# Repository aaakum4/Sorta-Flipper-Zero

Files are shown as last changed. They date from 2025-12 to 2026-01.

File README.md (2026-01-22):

Flipper Image

# Sorta-Flipper-Zero by aaakum4 (Jake)

At the cost of a flipper zero, I thought that I may never own one. Then I found a hackster.io page that went through a full DIY and cheap Flipper Zero and I thought I'd try it myself with some changes. With this project, I should also learn a ton about PCB's and how electronics work.

V1 is a modular based project to ensure that it will work as planned, then, , I will completely custom make it for V2. 

Features: 
- Bluetooth Low Energy (BLE)
- Sub-GHz RF support (433 MHz)
- NFC / RFID functionality
- Infrared (IR) transmit and receive
- On-device display
- Physical navigation and action buttons
- Audible feedback via buzzer
- MicroSD card storage
- USB-C connectivity
- External antenna support

Not included (compared to a standard Flipper): 
- iButton / 1-Wire support - Capacitive touch input
- Internal battery charging and management
- Integrated antennas
- Fully enclosed, consumer-ready housing (I will make one for v2)

## Step 1 - Looking at the Flipper Zero Hardware

Before starting this project, I went through the Flipper Zero hardware documentation to understand how the device is built and what components it uses.

https://docs.flipper.net/zero/development/hardware/tech-specs
https://docs.flipper.net/zero/development/hardware/schematic

<p align="center">

</p>

From this, I created the table below listing the main hardware blocks used in the Flipper Zero.
This table is used as a reference to understand the system, not something to copy directly.

### Flipper Zero – Hardware Component Overview

<p align="center">
Screenshot 2025-12-19 at 7 44 55 pm
</p>

### Simplifying the Design (v1)
To keep the first version realistic and achievable, a few things were intentionally simplified.

#### USB Power Only
The device is powered only through USB, with no internal rechargeable battery.
This removes a lot of complexity around battery charging and safety, and makes early testing much easier. Portability isn’t the focus for the first version.

#### BLE Using a Module or Dev Board
Instead of designing a full BLE RF circuit, this project uses either an STM32WB5MMG module or a NUCLEO-WB55RG during early development.
This avoids antenna tuning issues and lets me focus more on firmware and overall system behaviour.

#### Simpler Sub-1 GHz Antenna
The Flipper Zero uses an antenna multiplexer to optimise different Sub-1 GHz bands. For this project, that part is left out.
A single antenna is used instead, which means reduced range, but much simpler hardware and easier bring-up.

#### Physical Reset Button
Rather than copying the Flipper Zero’s reset button combination logic, this design uses a dedicated reset button.
This keeps the schematic simpler and is more practical while debugging.

## Step 2 - v1 Hardware Selection (Module Based)
Based on the Flipper Zero reference design and the simplifications outlined above, the following components were chosen for the v1 module-based prototype.
This list reflects what will actually be used in the first working version of the project.

V1 - Selected Components:

<p align="center">
Screenshot 2025-12-19 at 8 00 04 pm
</p>

## Step 3 – Schematic Design

With the overall architecture defined, I moved on to creating the full schematic in KiCad. The goal at this stage was to produce a complete, electrically correct design that could realistically be turned into a PCB, while still keeping the project modular and easy to iterate on.

I started by placing the STM32WB5MMGH6TR module and wiring all required power pins according to ST’s reference designs. This included separating the digital and analog supplies, tying VREF+ to VDDA, and correctly handling VBAT and VDDUSB. Decoupling capacitors were added close to each supply pin to ensure stable operation.

Next, the power system was designed around USB-C input. A main 3.3 V rail powers the MCU and core logic, while a second 3.3 V rail is used for external peripherals. 

Peripheral interfaces were then added. Instead of hard-coding specific modules, generic headers were used for NFC, Sub-1 GHz RF, display, IR, vibration, and expansion. These headers are labeled to match common module pinouts, allowing different breakout boards to be tested without changing the core design. Shared buses like SPI were carefully routed with separate chip-select signals.

Finally, the schematic was cleaned up and checked for electrical correctness. ERC warnings were addressed, unused pins were left intentionally for future use, and the design was reviewed to ensure it matched the original goals of being practical, modular, and suitable for a first hardware revision.

<p align="center">
Screenshot 2025-12-20 at 10 05 20 pm
</p>

This step, to be honest, was kinda cooked. I went in a bit over my head with this and it took wayyyy longer than I had hoped and probably needed.

## Step 4 - Schematic fixes and cleanup

After the initial schematic was complete, I spent time going back through it to fix a number of electrical and structural issues flagged by ERC. This step was mainly about correcting mistakes rather than adding new features.

Most of the changes were around power domains, making sure VDD, VDDA, VREF+, VBAT, and VDDUSB were connected correctly and matched the STM32WB module datasheet. I cleaned up grounding, added and adjusted local decoupling capacitors, and removed a few incorrect connections that were previously masking ERC errors instead of solving them properly.

I also fixed the Bluetooth RF path, reworking the RF_OUT pin so it is routed through a DC-blocking capacitor to a u.FL connector. This replaces earlier incorrect handling of the RF pin and makes the onboard BLE functionality usable while keeping the design clean and standards-compliant.

<p align="center">
Screenshot 2025-12-22 at 11 09 07 pm
</p>

<p align="center">
Screenshot 2025-12-22 at 11 08 50 pm
</p>

This is an amazing sight, no ERC errors 🙏🏻

## Step 5 - Sorting and routing the board

I am now a new man...

This was my third time routing a PCB, and it was a mix of improvement… and pain. The Xiao MCU I used for the Macropad and the ESP32-S3-WROOM-1u for the development board don’t come close to the challenge I just faced. The STM32WB5MMG is tiny but packed with pins, making it a real test of patience. That said, I’m finally done, and I couldn’t be happier.

There were multiple reroutes along the way, mostly caused by pin congestion around the MCU and the sheer number of external connectors. Some compromises were necessary, like tighter clearances and smaller vias, but in the end, the board reached a fully routable and manufacturable state.

While it’s not perfect, this routing pass made me really proud of how far I’ve come since the Macropad project. It was a clear reminder that schematics are the easy part—routing is where designs are truly made or broken.

For this project, I worked with a 4-layer board (my first board over 2 layers) to manage density and RF performance, especially around the RF/Bluetooth section. I created a dedicated antenna keep-out zone to avoid copper interference, routed USB D+ and D− as a matched, parallel pair to maintain signal integrity, and widened power traces to 0.5 mm to reduce voltage drop.

Given the tight board size, I had to selectively use smaller vias and reduced trace widths in congested areas to complete the routing without violating design rules. To make assembly easier, I also added silkscreen boxes around each functional module, improving clarity and helping with placement. Looking back, having dedicated GND and +3.3 V layers definitely made this step much more manageable compared to what it would’ve been without them.

### The board

Size: 125mm x 70mm (quite alot bulkier than a normal flipper, I have no clue how they do it)
Vias:
1) Defult: 0.6 x 0.3
2) Smaller (Due to cramped space): 0.45 x 0.2
Routes:
1) Defult: Clearance = 0.2, Width = 0.2
2) Power: Clearance = 0.2, Width = 0.5
3) Smaller: Clearance = 0.2, Width = 0.15

<p align="center">

</p>

#### Layer 1:
<p align="center">

</p>

#### Layer 2: GND
<p align="center">

</p>

#### Layer 3: +3V3
<p align="center">

</p>

#### Layer 4:
<p align="center">

</p>

#### 3D:
<p align="center">

</p>

<p align="center">

</p>

Estimated Time:
~2 hours of planning & component placement
~6 to 8 hours of routing + rerouting
~2 to 3 hours of cleanup, checks, and second-guessing everything

(Plus bonus time staring at the screen being stupid)

## Step ??? - Spontaneous Micro Project

For v2 of the Sorta Flipper Zero, I’ll most likely need to make a copper trace antenna for the NFC. For V1, I’m using a module, but I didn’t want to jump into V2 blindly. I decided to spend some time understanding how the module works, what I can bridge across, and even built my own small NFC card as an introduction to what I’ll need to do in V2.

Here’s the datasheet for the NFC module I hope to use: ST X-NUCLEO-NFC08A1

One thing I quickly noticed is that the antenna matters a lot. The orientation, size, and shape of the coil strongly affect the read range, and even small changes in trace layout or nearby copper can weaken the signal. This made it clear that designing a custom antenna will require careful attention.

I also learned that matching the antenna to the module is critical. The module expects the antenna to have roughly the right inductance; otherwise, communication becomes unreliable. Experimenting with the card showed me how adding or removing a turn in the coil noticeably changes performance.

Using the module is convenient because it handles much of the tuning internally. But seeing it in action made it obvious that if I want a custom copper trace for V2, I’ll need to account for these details myself.

This is the PCB I made from a simple schematic. I originally included an LED, but removed it in the PCB for the sake of readability and clarity. The file is in its own folder.

#### PCB:
<p align="center">

</p>

#### 3D:
<p align="center">

</p>

<p align="center">

</p>

This step is not nesassary at all, but I truly found it really helpful with general understanding of this concept and I think it will be even more helpful when I make v2.

## Parts
Since alot of this iteration will be using modules there isn't that much soldering. Here is the parts list from JLCPCB PCBA.

<p align="center">

</p>

## Firmware

Generating OTP Data (Flipper Zero)

This project uses the Flipper Zero firmware OTP generation script (scripts/otp.py) derived from the official Flipper Zero firmware repository (licensed under GPL-3.0) to generate device-specific OTP data.

### Example:

```
cd flipperzero-firmware/scripts

./otp.py generate \
  --version $((0x0c)) \
  --firmware $((0x07)) \
  --body $((0x09)) \
  --connect $((0x06)) \
  --display "mgg" \
  --color "transparent" \
  --region "world" \
  --name "Greg" \
  myotp
```

**Warning**: OTP memory is one-time programmable.
Flashing incorrect data may permanently affect the device.

### Installing Firmware via qFlipper

https://github.com/flipperdevices/qFlipper.git
Firmware installation is performed using qFlipper, the official Flipper Zero desktop application.

1. Install qFlipper from the official Flipper Zero website
2. Connect the device via USB
3. Select the appropriate firmware package
4. Follow on-screen flashing instructions

This project may reference prebuilt firmware or OTP data derived from the Flipper Zero firmware repository. All such components remain licensed under GPL-3.0, and source code is provided in accordance with that license.

## ⚠️ Problem solving

The NFC chip used on the X‑NUCLEO expansion board is the ST25R3916B, which has a different IC identity value to the ST25R3916 used in the Flipper Zero. Although the two chips share the same register map and functionality, the firmware performs an identity check during initialisation, causing the driver to fail when the B variant is detected.

To resolve this, I forked the official Flipper Zero firmware repository (https://github.com/flipperdevices/flipperzero-firmware) and modified the NFC driver to accept the ST25R3916B IC identity. This allows the existing firmware to operate correctly with the alternative NFC hardware without affecting functionality.

The modified source code is available here:
https://github.com/aaakum4/flipperzero-firmware.git

## License

This project is licensed under the GNU General Public License v3.0 (GPL-3.0).

This project includes and is derived from code from:
- flipperzero-firmware by skotopes (Top contributor)
  Licensed under GPL-3.0

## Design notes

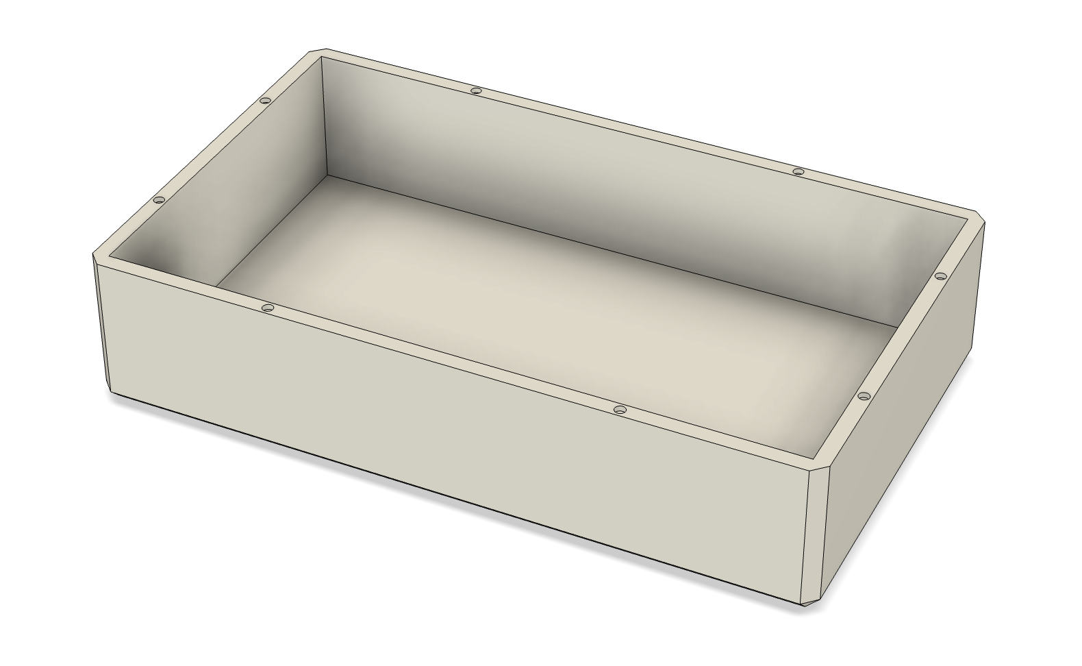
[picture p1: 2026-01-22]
CAD/Housing/Housing Bottom.png

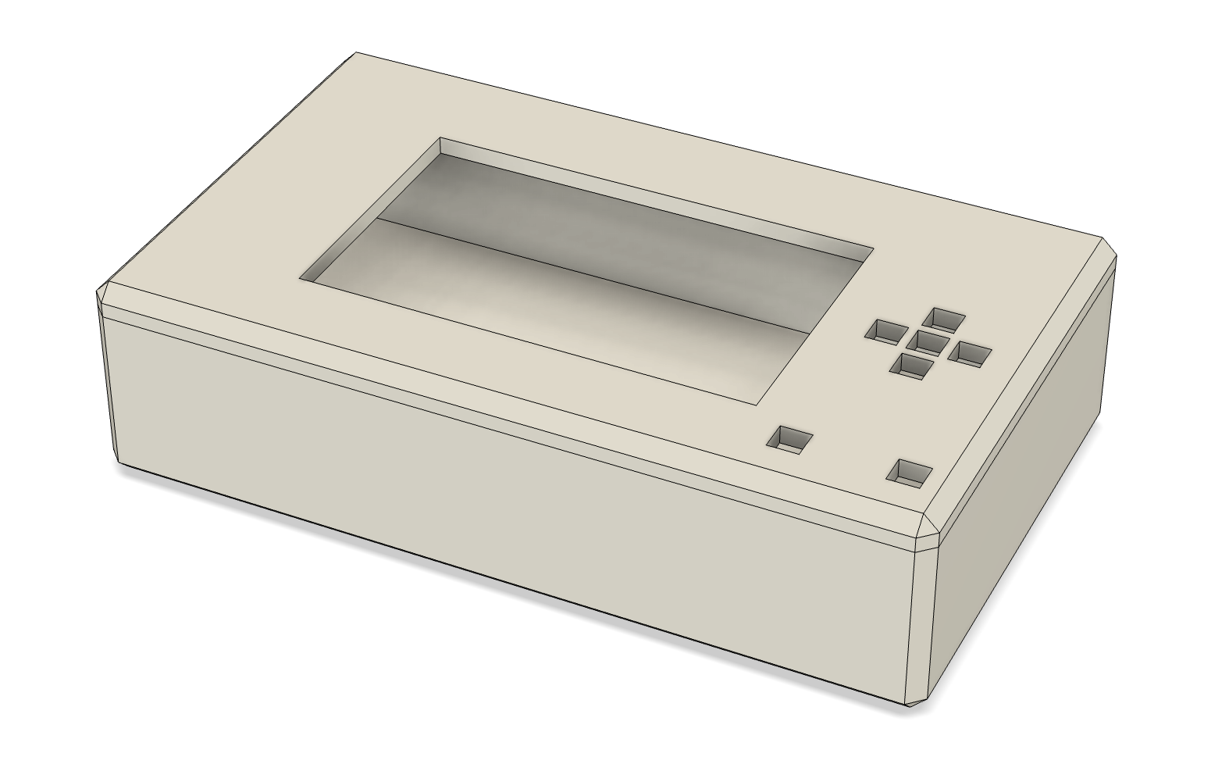
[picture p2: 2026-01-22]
CAD/Housing/Housing.png

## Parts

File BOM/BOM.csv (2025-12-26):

JLCPCB BOM Tool - BOM Matching
BOM name：Fipper Zero-JLCPCB Assembly Order.xlsx |  |  | Download Time：2025-12-26 21:10:08 |  |  |  | * Our matching results are updated in real-time, but stock and prices may change. If it's been over 24 hours, please re-match before placing your order.
PCB Assembled Qty：5 |  |  | Est. Total Price：65.3443
Your BOM |  |  |  |  | Matched Parts |  |  |  |  |  |  | Order Information
Top Designator | Bottom Designator | Comment | Footprint | JLCPCB Part # | Matches | Part # | Manufacturer | Footprint | Description | Category | Warning | JLCPCB Part # | Product link | Lib Type | Qty | Source | Total Price ($)
BZ1 |  | Buzzer | BUZ-TH_BD9.0-P4.00-D0.6-FD |  | Select by Customer | QMB-09B-03 | Jiangsu Huaneng Elec | 插件,D=9mm | -20℃~+70℃ 2.7kHz 2V~5V 3V 5.7mm 50mA 85dB 9mm Electromagnetic Passive (Externally Driven) Plugin,D=9mm Buzzers ROHS | Buzzers |  | C96256 | https://jlcpcb.com/partdetail/Jiangsu_HuanengElec-QMB_09B03/C96256 | Extended | 6 | 6 JLCPCB | 0.6714
C2 |  | 1uF | C_0603_1608Metric |  | Select by Customer | CL10A105KA8NNNC | Samsung Electro-Mechanics | 0603 | 1uF 25V X5R ±10% 0603 Multilayer Ceramic Capacitors MLCC - SMD/SMT ROHS | Multilayer Ceramic Capacitors MLCC - SMD/SMT |  | C5673 | https://jlcpcb.com/partdetail/6132-CL10A105KA8NNNC/C5673 | Extended | 20 | 20 JLCPCB | 0.086
C4,C5,C7,C6,C3,C1 |  | 100nF | C_0603_1608Metric |  | Select by Customer | CL10B104KA8NNNC | Samsung Electro-Mechanics | 0603 | 100nF 25V X7R ±10% 0603 Multilayer Ceramic Capacitors MLCC - SMD/SMT ROHS | Multilayer Ceramic Capacitors MLCC - SMD/SMT |  | C1590 | https://jlcpcb.com/partdetail/1942-CL10B104KA8NNNC/C1590 | Extended | 40 | 40 JLCPCB | 0.132
C8 |  | 4.7uF | C_0805_2012Metric |  | Select by Customer | CL21A475KOFNNNE | Samsung Electro-Mechanics | 0805 | 16V 4.7uF X5R ±10% 0805 Multilayer Ceramic Capacitors MLCC - SMD/SMT ROHS | Multilayer Ceramic Capacitors MLCC - SMD/SMT |  | C1746 | https://jlcpcb.com/partdetail/2098-CL21A475KOFNNNE/C1746 | Extended | 20 | 20 JLCPCB | 0.288
CP3,CP1,CP2 |  | 10u | C_0805_2012Metric |  | Select by Customer | CL21A106KAYNNNE | Samsung Electro-Mechanics | 0805 | 10uF 25V X5R ±10% 0805 Multilayer Ceramic Capacitors MLCC - SMD/SMT ROHS | Multilayer Ceramic Capacitors MLCC - SMD/SMT |  | C15850 | https://jlcpcb.com/partdetail/16532-CL21A106KAYNNNE/C15850 | Basic | 25 | 25 JLCPCB | 0.2475
D1 |  | D_Schottky | D_SOD-123 |  | Select by Customer | SS14 | MDD(Microdiode Semiconductor) | SMA(DO-214AC) | -55℃~+150℃ 1A 25A 300uA@40V 40V 550mV@1A Independent SMA(DO-214AC) Schottky Diodes ROHS | Schottky Diodes |  | C2480 | https://jlcpcb.com/partdetail/MDD_Microdiode_Semiconductor-SS14/C2480 | Basic | 15 | 15 JLCPCB | 0.2265
J5 |  | Conn_02x04_Odd_Even | PinHeader_2x04_P2.54mm_Vertical |  | Select by Customer | 2.54-1*40P直针 | BOOMELE(Boom Precision Elec) | 插件,P=2.54mm | -25℃~+85℃ 1 1x40P 2.54mm 2.5mm 3A 3mm 40P 6mm Black Brass Gold Pin Header Through Hole Plugin,P=2.54mm Pin Headers ROHS | Pin Headers | 1.Multiple lines in the BOM have been matched to the same part. Please check if the matching is correct. ; | C2337 | https://jlcpcb.com/partdetail/2712-2_54_1_40P/C2337 | Extended | 0 | 0 JLCPCB | 0
J6 |  | iButtonConnector | PinHeader_1x02_P2.54mm_Vertical |  | Select by Customer | 2.54-1*40P直针 | BOOMELE(Boom Precision Elec) | 插件,P=2.54mm | -25℃~+85℃ 1 1x40P 2.54mm 2.5mm 3A 3mm 40P 6mm Black Brass Gold Pin Header Through Hole Plugin,P=2.54mm Pin Headers ROHS | Pin Headers | 1.Multiple lines in the BOM have been matched to the same part. Please check if the matching is correct. ; | C2337 | https://jlcpcb.com/partdetail/2712-2_54_1_40P/C2337 | Extended | 0 | 0 JLCPCB | 0
J7 |  | MicroSDCard | PinHeader_1x06_P2.54mm_Vertical |  | Select by Customer | 2.54-1*40P直针 | BOOMELE(Boom Precision Elec) | 插件,P=2.54mm | -25℃~+85℃ 1 1x40P 2.54mm 2.5mm 3A 3mm 40P 6mm Black Brass Gold Pin Header Through Hole Plugin,P=2.54mm Pin Headers ROHS | Pin Headers | 1.Multiple lines in the BOM have been matched to the same part. Please check if the matching is correct. ; | C2337 | https://jlcpcb.com/partdetail/2712-2_54_1_40P/C2337 | Extended | 0 | 0 JLCPCB | 0
J8 |  | Switch | PinHeader_1x02_P2.54mm_Vertical |  | Select by Customer | 2.54-1*40P直针 | BOOMELE(Boom Precision Elec) | 插件,P=2.54mm | -25℃~+85℃ 1 1x40P 2.54mm 2.5mm 3A 3mm 40P 6mm Black Brass Gold Pin Header Through Hole Plugin,P=2.54mm Pin Headers ROHS | Pin Headers | 1.The comment (2.54-1*40P直针) of this part does not match the one (Switch) provided in your BOM. Please confirm; 2.Multiple lines in the BOM have been matched to the same part. Please check if the matching is correct. ; | C2337 | https://jlcpcb.com/partdetail/2712-2_54_1_40P/C2337 | Extended | 0 | 0 JLCPCB | 0
J14 |  | Conn_01x13 | PinHeader_1x13_P2.54mm_Vertical |  | Select by Customer | 2.54-1*40P直针 | BOOMELE(Boom Precision Elec) | 插件,P=2.54mm | -25℃~+85℃ 1 1x40P 2.54mm 2.5mm 3A 3mm 40P 6mm Black Brass Gold Pin Header Through Hole Plugin,P=2.54mm Pin Headers ROHS | Pin Headers | 1.Multiple lines in the BOM have been matched to the same part. Please check if the matching is correct. ; | C2337 | https://jlcpcb.com/partdetail/2712-2_54_1_40P/C2337 | Extended | 0 | 0 JLCPCB | 0
J15 |  | Conn_01x18 | Flipper_Zero_Straight |  | Select by Customer | 2.54-1*40P直针 | BOOMELE(Boom Precision Elec) | 插件,P=2.54mm | -25℃~+85℃ 1 1x40P 2.54mm 2.5mm 3A 3mm 40P 6mm Black Brass Gold Pin Header Through Hole Plugin,P=2.54mm Pin Headers ROHS | Pin Headers | 1.Multiple lines in the BOM have been matched to the same part. Please check if the matching is correct. ; | C2337 | https://jlcpcb.com/partdetail/2712-2_54_1_40P/C2337 | Extended | 0 | 0 JLCPCB | 0
J16 |  | Conn_Coaxial | U.FL_Hirose_U.FL-R-SMT-1_Vertical |  | Select by Customer | U.FL-R-SMT-1(10) | HRS(Hirose) | SMD | -40℃~+90℃ 1 1.25mm 2mm 50Ω 6GHz Board Side IPEX Male Pin SMD Coaxial Connectors (RF) ROHS | Coaxial Connectors (RF) |  | C88373 | https://jlcpcb.com/partdetail/HRS_Hirose-U_FL_R_SMT_1_10/C88373 | Extended | 5 | 5 JLCPCB | 0.947
R17,RX1,R7,R12,R4,R5,R19,R6,R10,R9,R8,R2,R14,R3,RX2,R13,R16,R21,R15,R20,R11,R1 |  | 47 | R_0603_1608Metric |  | Select by Customer | GZ1608D601TF | Sunlord | 0603 | -55℃~+125℃ 1 200mA 450mΩ 600Ω@100MHz ±25% 0603 Ferrite Beads ROHS | Ferrite Beads | 1.The comment (GZ1608D601TF) of this part does not match the one (47) provided in your BOM. Please confirm; 2.There may be multiple types of parts, but one type of part has been matched. Please check.; | C1002 | https://jlcpcb.com/partdetail/Sunlord-GZ1608D601TF/C1002 | Basic | 116 | 116 JLCPCB | 0.7772
R18,RU2,RU1,RP1 |  | 5.1k | R_0603_1608Metric |  | Select by Customer | 0402WGF5101TCE | UNI-ROYAL(Uniroyal Elec) | 0402 | -55℃~+155℃ 5.1kΩ 50V 62.5mW Thick Film Resistor ±1% ±100ppm/℃ 0402 Chip Resistor - Surface Mount ROHS | Chip Resistor - Surface Mount | 1.The comment (0402WGF5101TCE) of this part does not match the one (5.1k) provided in your BOM. Please confirm; 2.There may be multiple types of parts, but one type of part has been matched. Please check.; | C25905 | https://jlcpcb.com/partdetail/26648-0402WGF5101TCE/C25905 | Basic | 30 | 30 JLCPCB | 0.015
R22 |  | 10 | R_0603_1608Metric |  | Select by Customer | 0603WAF100JT5E | UNI-ROYAL(Uniroyal Elec) | 0603 | -55℃~+155℃ 100mW 10Ω 75V Thick Film Resistor ±1% ±400ppm/℃ 0603 Chip Resistor - Surface Mount ROHS | Chip Resistor - Surface Mount | 1.The comment (0603WAF100JT5E) of this part does not match the one (10) provided in your BOM. Please confirm; | C22859 | https://jlcpcb.com/partdetail/23586-0603WAF100JT5E/C22859 | Basic | 20 | 20 JLCPCB | 0.02
R23 |  | 0 | R_0402_1005Metric |  | Select by Customer | PA0402-R-070RL | YAGEO | 0402 | -55℃~+125℃ 0Ω 62.5mW ±150ppm/℃ 0402 Chip Resistor - Surface Mount ROHS | Chip Resistor - Surface Mount |  | C4044221 | https://jlcpcb.com/partdetail/YAGEO-PA0402_R070RL/C4044221 | Extended | 7 | 7 JLCPCB | 0.9121
SW4,SW5,SW1,SW3,SW7,SW6,SW2 |  | SW_Push | SW_PUSH_6mm |  | Select by Customer | HX-6x6x7.3-TP FT square button | hanxia | SMD,6x6mm | SMD,6x6mm Tactile Switches ROHS |  |  | C49234152 | https://jlcpcb.com/partdetail/C49234152 | Extended | 35 | 35 JLCPCB | 0.9765
U1 |  | STM32WB5MMGH6TR | LCC-LGA-86_L11.0-W7.3_STM32WB5MMGH6TR |  | Select by Customer | STM32WB5MMGH6TR | STMicroelectronics | LFLGA-86 | -40℃~+85℃ -96dBm 1.71V~3.6V 2.4GHz 2.4GHz~2.4835GHz 2Mbps 6dBm SPI ZigBee LFLGA-86 RF Transceiver ICs ROHS | RF Transceiver ICs |  | C5184586 | https://jlcpcb.com/partdetail/STMicroelectronics-STM32WB5MMGH6TR/C5184586 | Extended | 5 | 5 JLCPCB | 58.108
UP2,UP1 |  | AP2112K-3.3 | SOT-23-5 |  | Select by Customer | AP2112K-3.3TRG1 | TECH PUBLIC | SOT-23-5 | -、50dB@(10kHz)、70dB@(1kHz)、70dB@(1kHz)、70dB@(1kHz)、75dB@(1kHz)、75dB@(1kHz) 1.5uA、2uA、2uA、5uA、5uA、10uA、10uA、25uA 1、1、1、1、1、1 200mA、300mA、500mA、500mA、600mA、600mA、600mA、800mA 200mV@(300mA)、300mV@(100mA)、320mV@(600mA)、320mV@(600mA)、350mV@(100mA)、400mV@(800mA)、420mV@(100mA)、800mV@(600mA) 3.3V、1.2V、2.5V、3V、5V、3V、3V、3V 5.5V、5.5V、5.5V、5.5V、6V、20V、20V、24V Fixed、Fixed、Fixed、Fixed、Fixed、Fixed、Fixed、Fixed Over Temperature Protection、Over Current Protection、Over Temperature Protection、Ove | Voltage Regulators - Linear, Low Drop Out (LDO) Regulators |  | C23380830 | https://jlcpcb.com/partdetail/TECHPUBLIC-AP2112K_33TRG1/C23380830 | Extended | 12 | 12 JLCPCB | 1.0776
USB1 |  | USB_C_Receptacle_USB2.0_16P | USB_C_Receptacle_HRO_TYPE-C-31-M-12 |  | Select by Customer | TYPE-C-31-M-12 | Korean Hroparts Elec | SMD | -30℃~+80℃ 1 10,000 cycles 16P 20V 5A 7.35mm Female Surface Mount, Right Angle Type-C SMD USB Connectors ROHS | USB Connectors |  | C165948 | https://jlcpcb.com/partdetail/Korean_HropartsElec-TYPE_C_31_M12/C165948 | Extended | 5 | 5 JLCPCB | 0.8595
EBay | Cost (USD) | Link
5V Mini Vibration Motor Module with High-Low Level PWM Control | 4.66 | https://www.ebay.com.au/itm/176796753894
Total: | 4.66
AliExpress | Cost (USD) | Link
125KHz RFID Module | 2.9 | https://www.aliexpress.com/item/1005006440663319.html?mp=1
LED Display | 4.89 | https://www.aliexpress.com/item/1005006160620381.html?mp=1
RF Transmitter and Reader | 1.07 | https://www.aliexpress.com/item/1005007728215137.html?mp=1
Total: | 8.86
DigiKey | Cost (USD) | Link
X-Nucleo NFC | 39.72 | https://www.digikey.com.au/en/products/detail/stmicroelectronics/X-NUCLEO-NFC08A1/16962233
STM32WB5MMGH6TR | 12.86 | https://www.digikey.com.au/en/products/detail/stmicroelectronics/STM32WB5MMGH6TR/13592597
Micro SD CARD DFR0229 | 5.51 | https://www.digikey.com.au/en/products/detail/dfrobot/DFR0229/6588460
Total: | 58.09

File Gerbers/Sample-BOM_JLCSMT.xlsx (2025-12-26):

Comment | Designator | Footprint | JLCPCB Part #（optional）
100uF | C1 | CAP-SMD_L3.5-W2.8 | C16133
15K | R5,R6 | R0603 | C22809
DC-005-20A_C136744 | DC1 | DC-IN-TH_DC-005-20A | C136744
Header-Female-2.54_1x8 | P2,P3 | HDR-TH_8P-P2.54-V | C27438
K2-1102DP-C4SW-04 | SW1 | KEY-TH_4P-L6.0-W6.0-P4.50-LS6.5 | C110153
ATMEGA328P-PU | U1 | DIP-28_L34.6-W7.3-P2.54-LS10.2-BL | C33901
670688000 | USB1 | USB-B-TH_67068-8000 | C114097

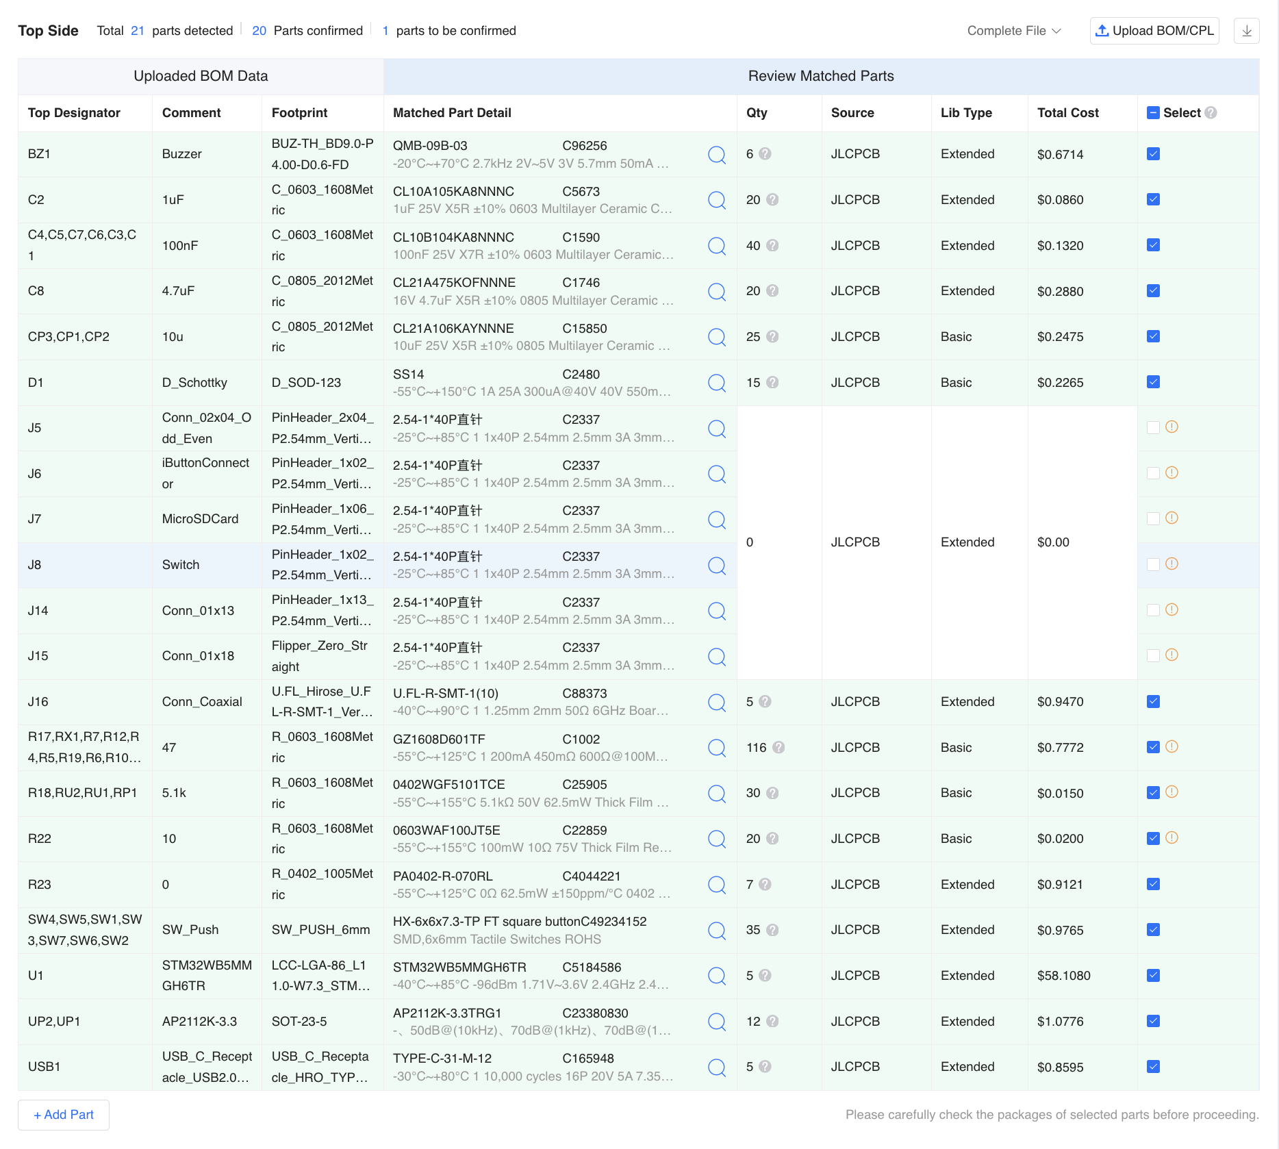
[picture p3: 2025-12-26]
BOM/BOM Image.png

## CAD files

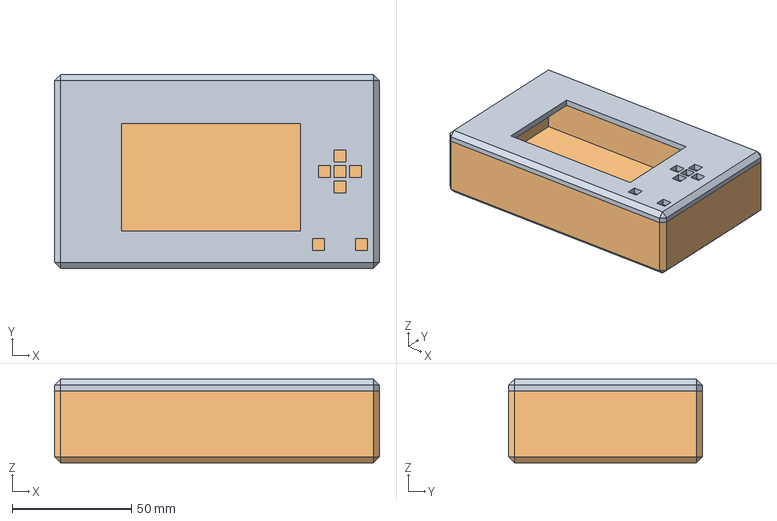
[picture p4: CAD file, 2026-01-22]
CAD/Housing/Basic Housing.step
136.0 x 81.0 x 35.0 mm

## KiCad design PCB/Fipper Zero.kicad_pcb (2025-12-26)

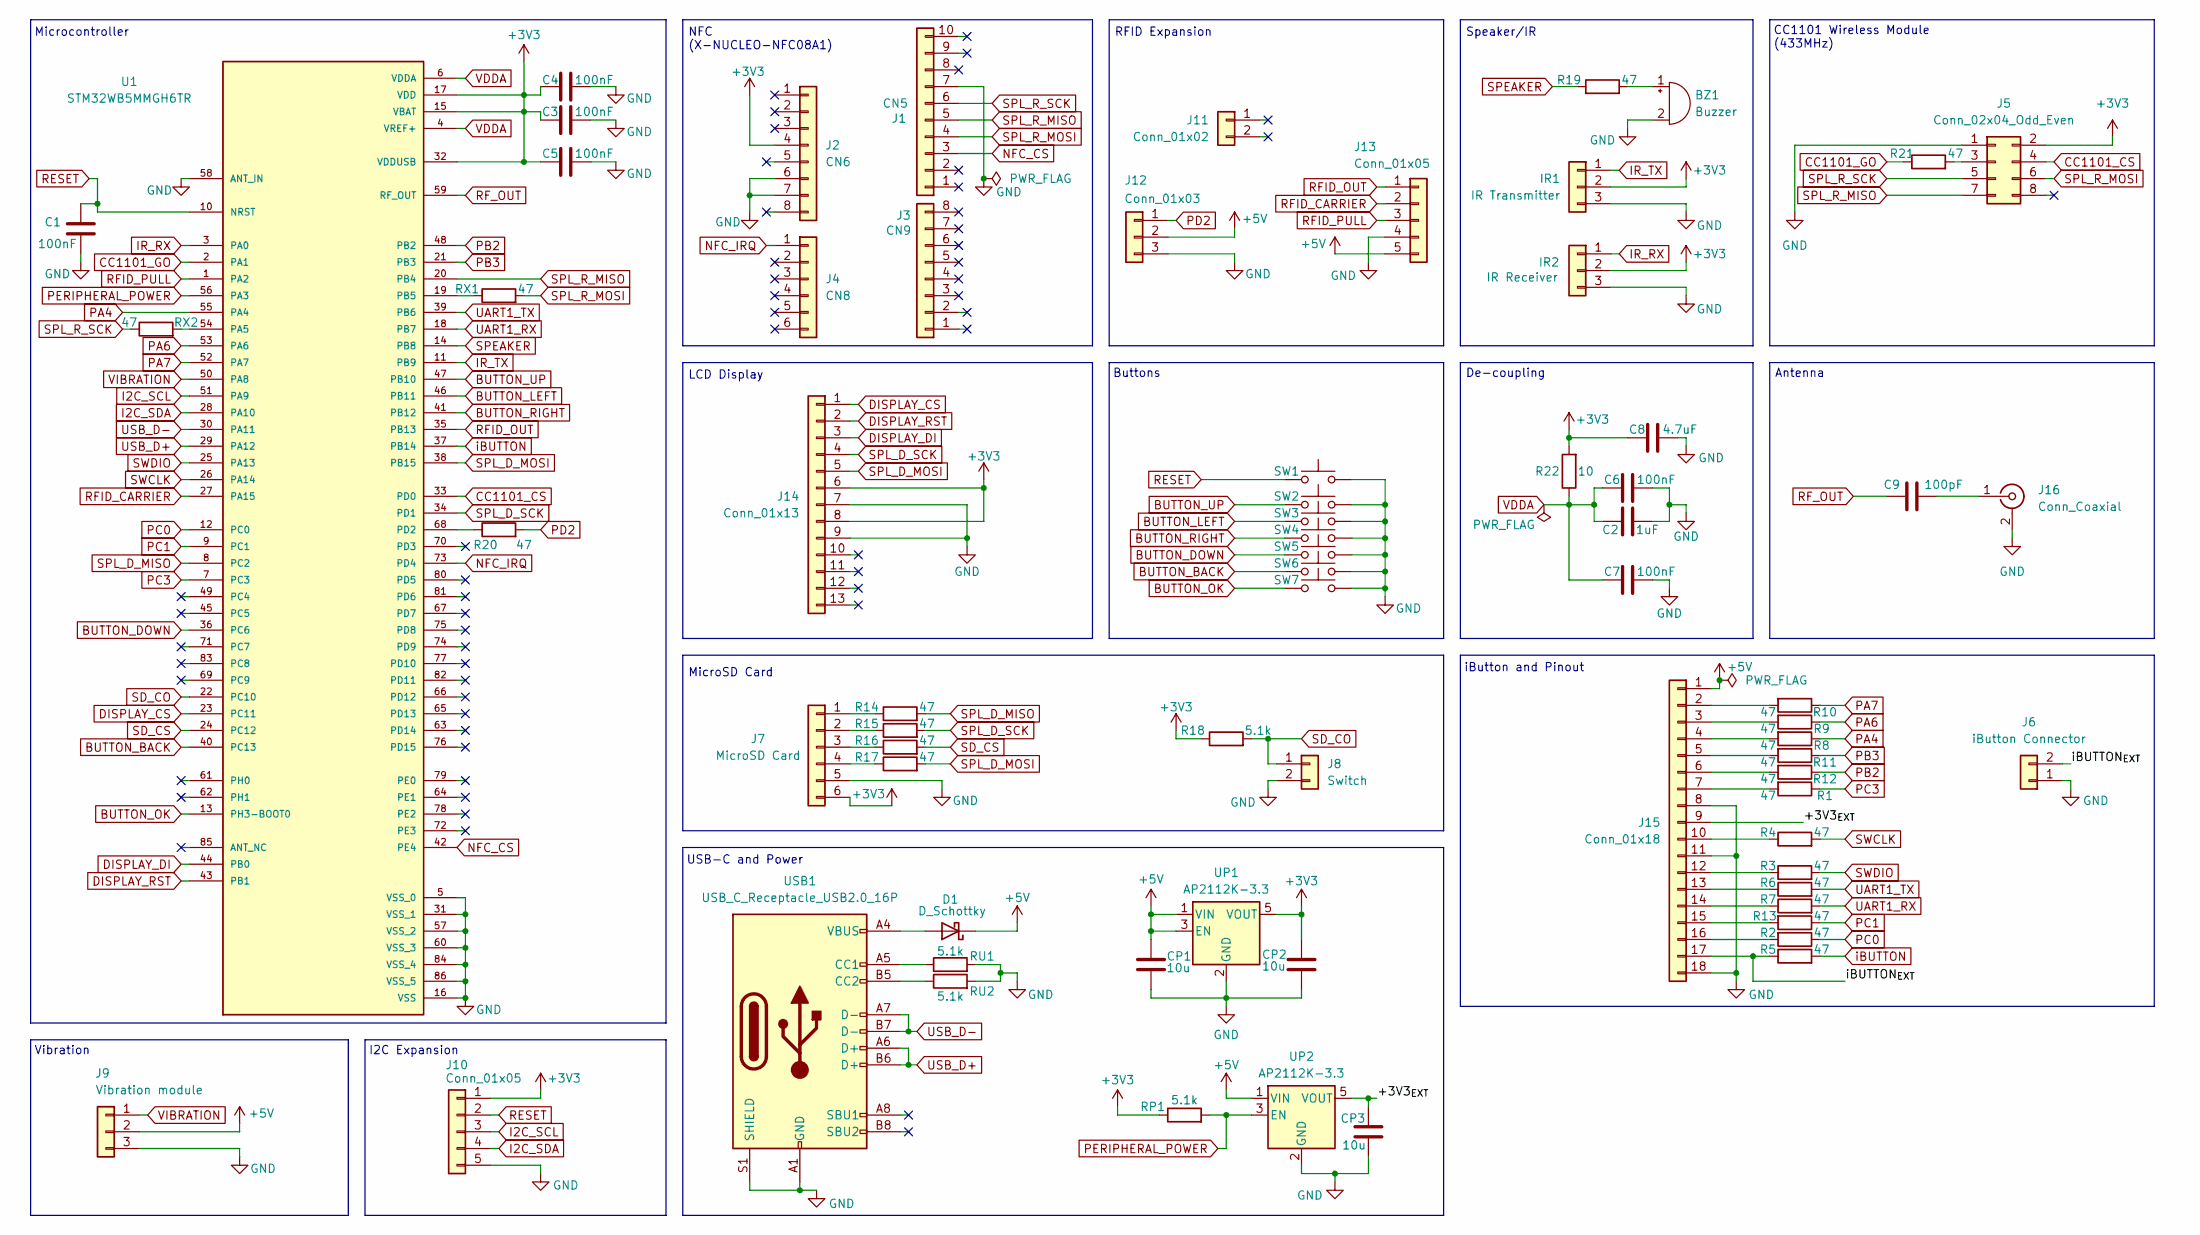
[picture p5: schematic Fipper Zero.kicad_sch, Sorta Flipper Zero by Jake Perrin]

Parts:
BZ1: Buzzer; BUZ-TH_BD9.0-P4.00-D0.6-FD
C1, C3, C4, C5, C6, C7: 100nF; C_0603_1608Metric
C2: 1uF; C_0603_1608Metric
C8: 4.7uF; C_0805_2012Metric
C9: 100pF; C_0402_1005Metric
CP1, CP2, CP3: 10u; C_0805_2012Metric
D1: D_Schottky; D_SOD-123
IR1: IR Transmitter; PinHeader_1x03_P2.54mm_Vertical
IR2: IR Receiver; PinHeader_1x03_P2.54mm_Vertical
J1: CN5; PinHeader_1x10_P2.54mm_Vertical
J2: CN6; PinHeader_1x08_P2.54mm_Vertical
J3: CN9; PinHeader_1x08_P2.54mm_Vertical
J4: CN8; PinHeader_1x06_P2.54mm_Vertical
J5: Conn_02x04_Odd_Even; PinHeader_2x04_P2.54mm_Vertical
J6: iButton Connector; PinHeader_1x02_P2.54mm_Vertical
J7: MicroSD Card; PinHeader_1x06_P2.54mm_Vertical
J8: Switch; PinHeader_1x02_P2.54mm_Vertical
J9: Vibration module; PinHeader_1x02_P2.54mm_Vertical
J10, J13: Conn_01x05; PinHeader_1x05_P2.54mm_Vertical
J11: Conn_01x02; PinHeader_1x02_P2.54mm_Vertical
J12: Conn_01x03; PinHeader_1x03_P2.54mm_Vertical
J14: Conn_01x13; PinHeader_1x13_P2.54mm_Vertical
J15: Conn_01x18; PinHeader_1x18_P2.54mm_Vertical
J16: Conn_Coaxial; U.FL_Hirose_U.FL-R-SMT-1_Vertical
R1, R2, R3, R4, R5, R6, R7, R8, R9, R10, R11, R12, R13, R14, R15, R16, R17, R19, R20, R21: 47; R_0603_1608Metric
R18: 5.1k; R_0603_1608Metric
R22: 10; R_0603_1608Metric
RP1: 5.1k; R_0603_1608Metric
RU1, RU2: 5.1k; R_0603_1608Metric
RX1, RX2: 47; R_0603_1608Metric
SW1, SW2, SW3, SW4, SW5, SW6, SW7: SW_Push; SW_PUSH_6mm
U1: STM32WB5MMGH6TR; LCC-LGA-86_L11.0-W7.3_STM32WB5MMGH6TR; PARTREV 8
UP1, UP2: AP2112K-3.3; SOT-23-5
USB1: USB_C_Receptacle_USB2.0_16P; USB_C_Receptacle_HRO_TYPE-C-31-M-12

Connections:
+3V3: C3.1, C4.1, C5.1, C8.1, CP2.1, IR1.2, IR2.2, J2.4, J5.2, J7.6, J10.1, J14.6, J14.8, R18.1, R22.2, RP1.1, U1.15 (VBAT), U1.17 (VDD), U1.32 (VDDUSB), UP1.5 (VOUT)
+5V: CP1.1, D1.1 (K), J9.2, J12.2, J13.5, J15.1, UP1.1 (VIN), UP1.3 (EN), UP2.1 (VIN)
/+3V3_{EXT}: CP3.1, J15.9, UP2.5 (VOUT)
/iBUTTON_{EXT}: J6.2, J15.17, R5.1
BUTTON_BACK: SW6.1, U1.40 (PC13)
BUTTON_DOWN: SW5.1, U1.36 (PC6)
BUTTON_LEFT: SW3.1, U1.46 (PB11)
BUTTON_OK: SW7.1, U1.13 (PH3-BOOT0)
BUTTON_RIGHT: SW4.1, U1.41 (PB12)
BUTTON_UP: SW2.1, U1.47 (PB10)
CC1101_CS: J5.4, U1.33 (PD0)
CC1101_GO: R21.1, U1.2 (PA1)
DISPLAY_CS: J14.1, U1.23 (PC11)
DISPLAY_DI: J14.3, U1.44 (PB0)
DISPLAY_RST: J14.2, U1.43 (PB1)
GND: BZ1.2 (-), C1.2, C2.2, C3.2, C4.2, C5.2, C6.2, C7.2, C8.2, CP1.2, CP2.2, CP3.2, IR1.3, IR2.3, J1.7, J2.6, J2.7, J5.1, J6.1, J7.5, J8.2, J9.3, J10.5, J12.3, J13.4, J14.7, J14.9, J15.8, J15.11, J15.18, J16.2 (Ext), RU1.2, RU2.2, SW1.2, SW2.2, SW3.2, SW4.2, SW5.2, SW6.2, SW7.2, U1.5 (VSS_0), U1.16 (VSS), U1.31 (VSS_1), U1.57 (VSS_2), U1.58 (ANT_IN), U1.60 (VSS_3), U1.84 (VSS_4), U1.86 (VSS_5), UP1.2 (GND), UP2.2 (GND), USB1.A1 (GND), USB1.A12 (GND), USB1.B1 (GND), USB1.B12 (GND), USB1.S1 (SHIELD)
I2C_SCL: J10.3, U1.51 (PA9)
I2C_SDA: J10.4, U1.28 (PA10)
IR_RX: IR2.1, U1.3 (PA0)
IR_TX: IR1.1, U1.11 (PB9)
NFC_CS: J1.3, U1.42 (PE4)
NFC_IRQ: J4.1, U1.73 (PD4)
unnamed: BZ1.1 (+), R19.2
unnamed: D1.2 (A), USB1.A4 (VBUS), USB1.A9 (VBUS), USB1.B4 (VBUS), USB1.B9 (VBUS)
unnamed: J5.3, R21.2
unnamed: J7.1, R14.1
unnamed: J7.2, R15.1
unnamed: J7.3, R16.1
unnamed: J7.4, R17.1
unnamed: J15.2, R10.2
unnamed: J15.3, R9.2
unnamed: J15.4, R8.2
unnamed: J15.5, R11.2
unnamed: J15.6, R12.2
unnamed: J15.7, R1.2
unnamed: J15.10, R4.1
unnamed: J15.12, R3.1
unnamed: J15.13, R6.1
unnamed: J15.14, R7.1
unnamed: J15.15, R13.2
unnamed: J15.16, R2.2
unnamed 41: C9.2, J16.1 (In); also elsewhere on the board
unnamed: RX2.2, U1.54 (PA5)
unnamed: RX1.1, U1.19 (PB5)
unnamed: R20.1, U1.68 (PD2)
unnamed: RU1.1, USB1.A5 (CC1)
unnamed: RU2.1, USB1.B5 (CC2)
PA4: R8.1, U1.55 (PA4)
PA6: R9.1, U1.53 (PA6)
PA7: R10.1, U1.52 (PA7)
PB2: R12.1, U1.48 (PB2)
PB3: R11.1, U1.21 (PB3)
PC0: R2.1, U1.12 (PC0)
PC1: R13.1, U1.9 (PC1)
PC3: R1.1, U1.7 (PC3)
PD2: J12.1, R20.2
PERIPHERAL_POWER: RP1.2, U1.56 (PA3), UP2.3 (EN)
RESET: C1.1, J10.2, SW1.1, U1.10 (NRST)
RFID_CARRIER: J13.2, U1.27 (PA15)
RFID_OUT: J13.1, U1.35 (PB13)
RFID_PULL: J13.3, U1.1 (PA2)
RF_OUT: C9.1, U1.59 (RF_OUT); also elsewhere on the board
SD_CO: J8.1, R18.2, U1.22 (PC10)
SD_CS: R16.2, U1.24 (PC12)
SPEAKER: R19.1, U1.14 (PB8)
SPL_D_MISO: R14.2, U1.8 (PC2)
SPL_D_MOSI: J14.5, R17.2, U1.38 (PB15)
SPL_D_SCK: J14.4, R15.2, U1.34 (PD1)
SPL_R_MISO: J1.5, J5.7, U1.20 (PB4)
SPL_R_MOSI: J1.4, J5.6, RX1.2
SPL_R_SCK: J1.6, J5.5, RX2.1
SWCLK: R4.2, U1.26 (PA14)
SWDIO: R3.2, U1.25 (PA13)
UART1_RX: R7.2, U1.18 (PB7)
UART1_TX: R6.2, U1.39 (PB6)
USB_D+: U1.29 (PA12), USB1.A6 (D+), USB1.B6 (D+)
USB_D-: U1.30 (PA11), USB1.A7 (D-), USB1.B7 (D-)
VDDA: C2.1, C6.1, C7.1, R22.1, U1.4 (VREF+), U1.6 (VDDA)
VIBRATION: J9.1, U1.50 (PA8)
iBUTTON: R5.2, U1.37 (PB14)

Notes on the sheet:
De-coupling
Buttons
MicroSD Card
CC1101 Wireless Module (433MHz)
NFC (X-NUCLEO-NFC08A1)
LCD Display
USB-C and Power
iButton and Pinout
Speaker/IR
Microcontroller
I2C Expansion
Vibration
RFID Expansion
Antenna

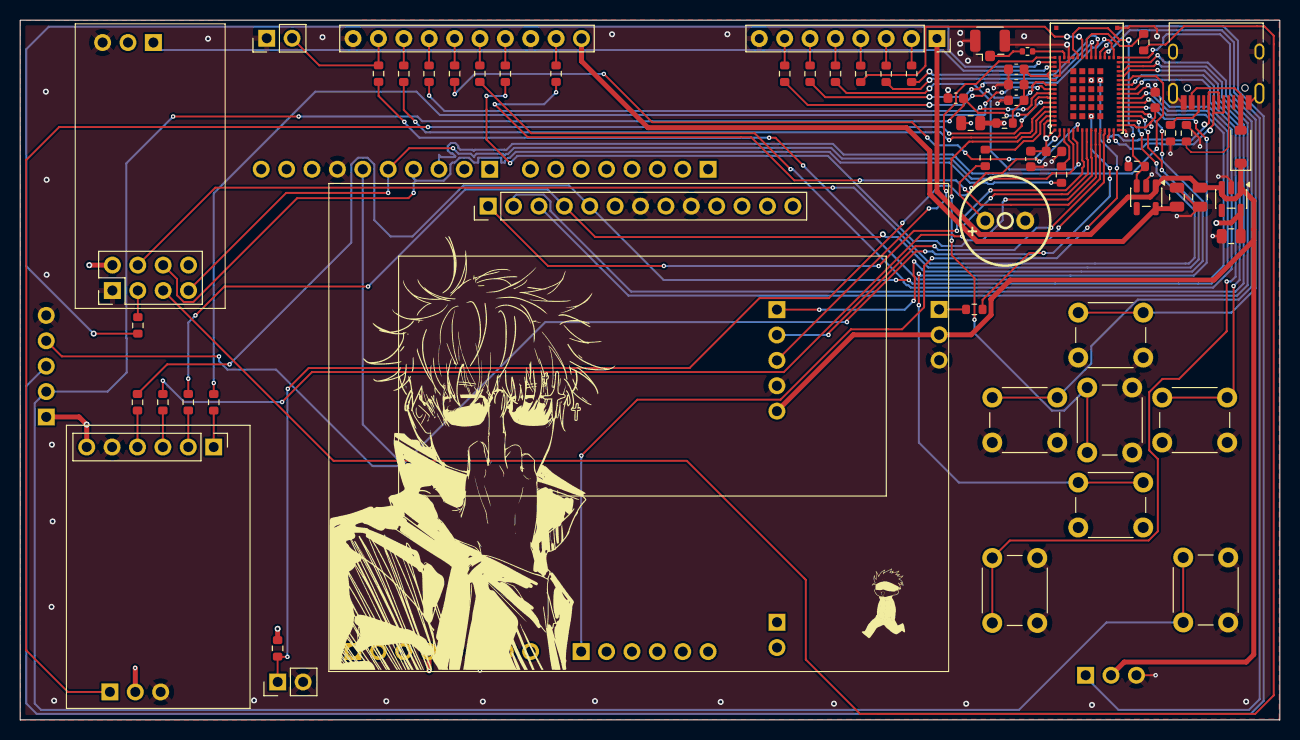
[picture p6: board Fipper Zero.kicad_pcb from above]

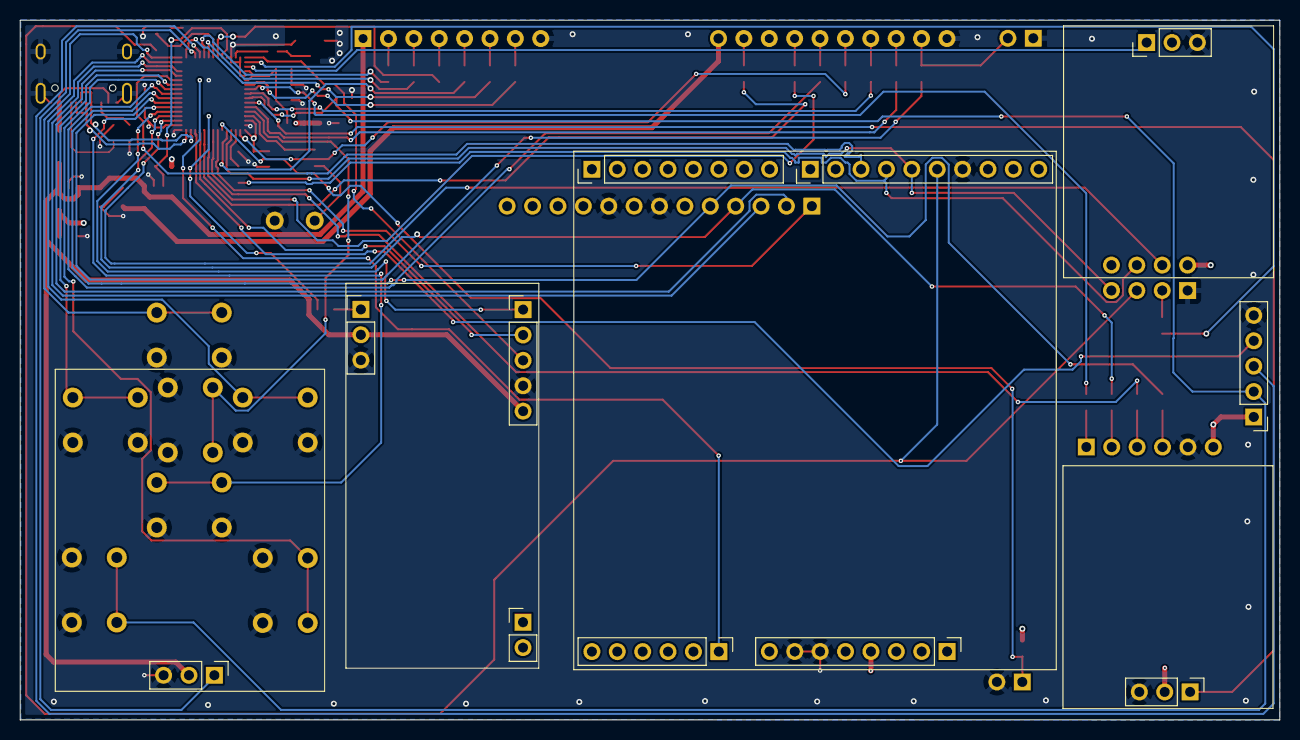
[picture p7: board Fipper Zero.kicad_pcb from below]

Board: 4 copper layers, 126.0 x 70.0 mm, 70 parts (11 on the bottom side), 80 nets.

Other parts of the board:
R23: 0; R_0402_1005Metric

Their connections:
unnamed 41: R23.2; also elsewhere on the board
RF_OUT: R23.1; also elsewhere on the board

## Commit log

2025-12-20 Document schematic design process in README
    Added detailed explanation of the schematic design process, including power system and peripheral interfaces.
2025-12-22 Document schematic fixes and cleanup in README
    Updated the README to reflect schematic fixes and cleanup details.
2025-12-22 Update README with hardware and schematic design steps
    Added sections on hardware overview and schematic design.
2025-12-22 Added v1.0 of the schematic
    [Fipper Zero.kicad_sch]
2025-12-24 Update README with sorting and routing notes
    Added notes on sorting and routing the board.
2025-12-24 Update PCB design notes in README
    Adjusted routing and via sizes for a compact PCB design.
2025-12-26 Revise README with project updates and V2 plans
    Updated project description and added details about V2 development, including antenna considerations and PCB design.
2025-12-26 NFC Micro Project Added
    [NFC Card.kicad_pcb, NFC Card.kicad_sch]
2026-01-22 Add parts list section to README
    Added a parts list section with an image from JLCPCB PCBA.
